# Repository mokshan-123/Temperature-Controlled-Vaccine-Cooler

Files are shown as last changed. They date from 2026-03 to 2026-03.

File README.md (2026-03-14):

# Smart Vaccine Temperature Monitoring System

A portable, low-cost vaccine temperature monitoring system designed for cold-chain transport in rural and low-resource settings.  
The system provides real-time temperature monitoring, configurable safety thresholds, and wireless alerts using ESP-NOW communication.

---

## 1. Overview

Vaccines must be maintained within a strict temperature range (typically 2–8°C) to preserve potency. During transportation(especially in rural outreach) temperature excursions may go undetected, leading to vaccine spoilage and wastage.

This project presents a smart monitoring solution that:

- Continuously measures internal temperature
- Wirelessly transmits data without Wi-Fi infrastructure
- Provides visual and audio alerts for temperature excursions
- Allows configurable temperature thresholds
- Operates on rechargeable battery power

The system is designed to be affordable, modular, and suitable for low-resource healthcare environments.

---

## 2. System Architecture

The system consists of two main subsystems:

### Transmitter Unit (Inside Vaccine Box)
- ESP8266 NodeMCU
- DS18B20 Digital Temperature Sensor
- Battery-powered
- Sends temperature data via ESP-NOW

### Receiver Unit (External Monitoring Module)
- ESP32-S3
- 0.96" OLED Display
- 4x4 Keypad for threshold configuration
- LED indicators (Safe / Warning / No Data)
- Active buzzer for alerts
- Receives data via ESP-NOW

### Communication Protocol
- ESP-NOW (peer-to-peer wireless protocol)
- No internet or router required
- Low-latency and energy-efficient

---

## 3. Key Features

- Real-time temperature monitoring
- Configurable upper and lower thresholds
- OLED live temperature display
- LED status indicators:
  - Green → Within safe range
  - Red (blinking) → Temperature excursion
  - Yellow → No data received
- Audible buzzer alerts
- Automatic timeout detection
- Battery-powered operation
- Designed for future Peltier cooling integration

---

## 4. Hardware Components

### Core Electronics
- ESP8266 NodeMCU (Transmitter)
- ESP32-S3 (Receiver)
- DS18B20 Waterproof Digital Temperature Sensor
- 0.96” OLED Display (I2C)
- 4x4 Matrix Keypad
- Active Buzzer
- LED Indicators
- 18650 Li-ion Battery
- Boost Converter Module

### Enclosure
- Insulated vaccine compartment
- Receiver housing with display and keypad
- Provision for future Peltier module integration

---

## 5. Firmware Architecture

### Transmitter Firmware (ESP8266)

Responsibilities:
- Initialize DS18B20 sensor
- Read temperature every 1 second
- Package data into structured format
- Transmit via ESP-NOW
- Handle sensor disconnection errors

Core logic:
- OneWire + DallasTemperature library
- ESP-NOW peer configuration
- Periodic data transmission

---

### Receiver Firmware (ESP32-S3)

Responsibilities:
- Receive temperature data via ESP-NOW callback
- Store latest reading
- Compare against user-defined thresholds
- Control buzzer and LED indicators
- Display temperature and limits on OLED
- Handle timeout detection (no data condition)
- Allow threshold input via keypad

Key Embedded Concepts Used:
- Interrupt-driven callback for wireless reception
- State-based LED logic
- Non-blocking buzzer toggling using millis()
- Timeout monitoring for communication reliability

---

## 6. Threshold Configuration

Users can enter threshold-setting mode using the keypad:

- Lower threshold input
- Upper threshold input
- Automatic correction if upper < lower
- Real-time display update

This allows flexibility for different vaccine temperature requirements.

---

## 7. Testing and Validation

The prototype was evaluated under lab and field-like conditions.

### Results

- Wireless range: 20–30 meters (line-of-sight)
- Sensor accuracy deviation: approximately ±0.5°C (compared to calibrated thermometer)
- Reliable threshold detection and alert triggering
- Stable OLED readout
- Sufficient battery performance for continuous monitoring

---

## 8. Regulatory Considerations

The device is intended as a low-risk monitoring accessory for vaccine cold-chain systems.

Likely classification:
- Class I (low-risk monitoring device)

Relevant standards considered:
- IEC 60601 (Electrical safety considerations)
- IEC 62304 (Medical device software lifecycle)
- WHO cold-chain guidelines
- Local Ministry of Health compliance requirements

Future iterations would require:
- Sensor validation testing
- Electrical safety compliance
- EMC testing
- Software documentation per medical device standards

---

## 9. Hardware Overview

### Circuit Diagram
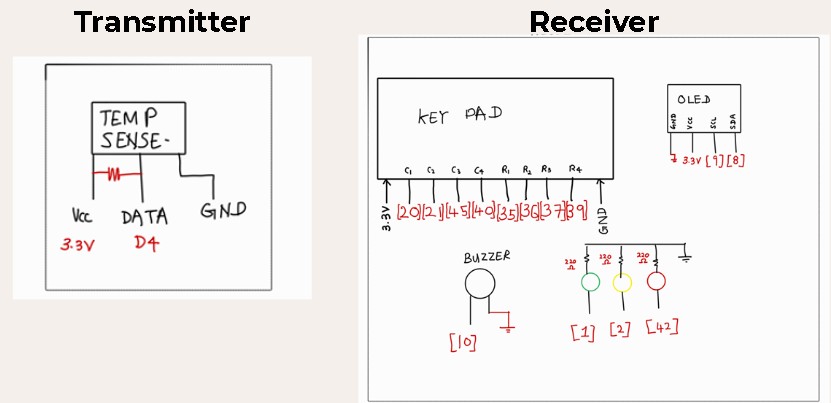
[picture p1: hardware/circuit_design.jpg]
Circuit


### Block Diagram
Block_diagram

### PCB Layout
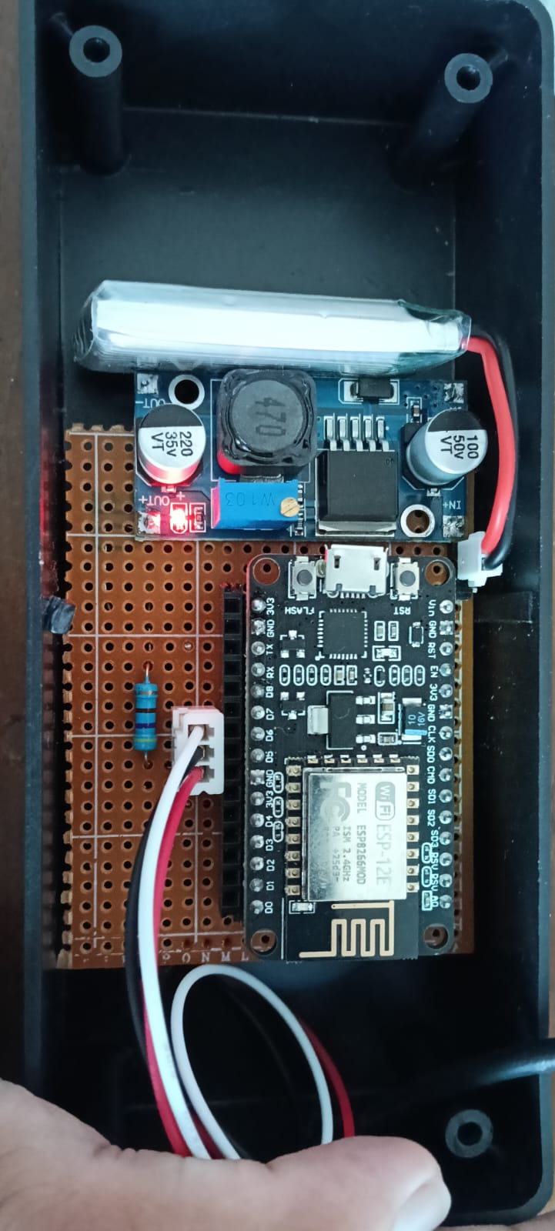
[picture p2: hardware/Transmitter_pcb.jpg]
Transmitter_PCB

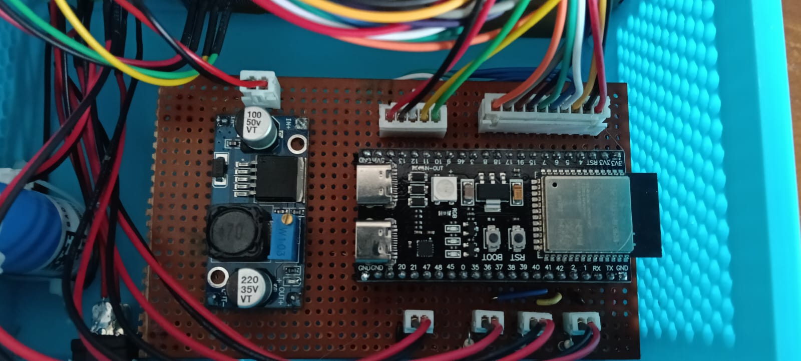
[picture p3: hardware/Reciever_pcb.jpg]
Reciever_PCB


### Enclosure Design
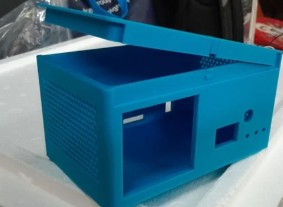
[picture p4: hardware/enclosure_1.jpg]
Enclosure_1

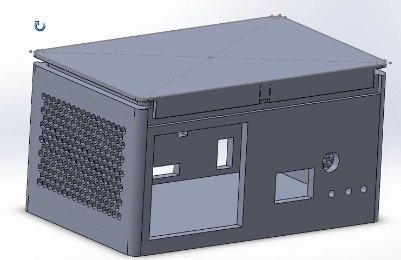
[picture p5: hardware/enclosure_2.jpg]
Enclosure_2

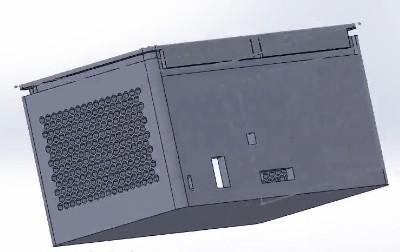
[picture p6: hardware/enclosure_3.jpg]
Enclosure_3


### Final product Assembly
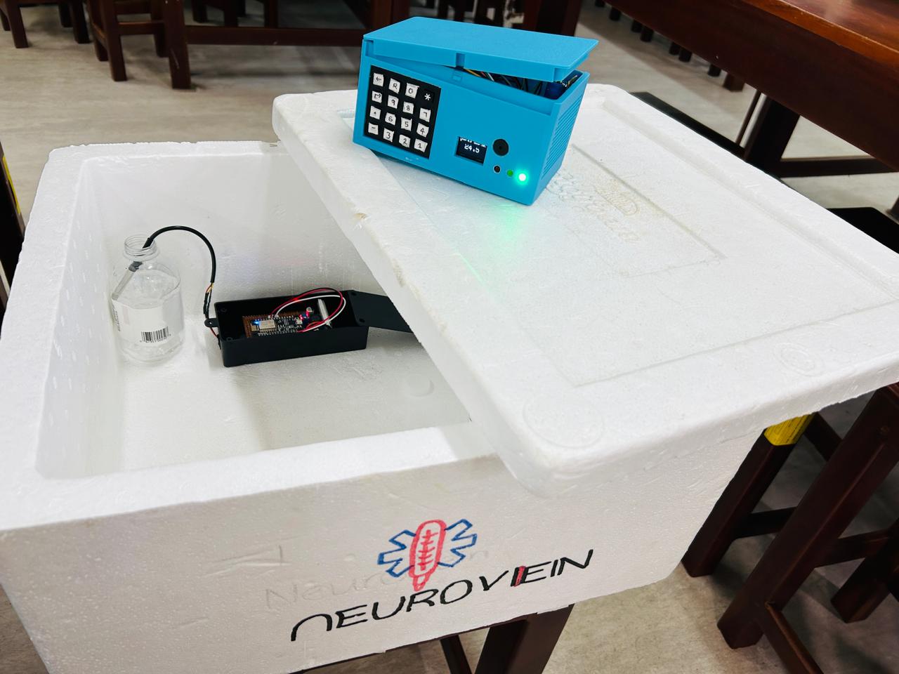
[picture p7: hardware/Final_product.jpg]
Final Product


---

## 10. Future Improvements

- Integration of Peltier-based active cooling
- Multi-sensor internal thermal mapping
- Solar charging module for remote deployment
- Cloud-based data logging
- Fault detection for sensor and communication errors
- Improved insulation materials
- Secure encrypted ESP-NOW transmission

---

## 11. Budget Summary

Total prototype cost: ~8410 LKR

Major cost contributors:
- ESP32-S3
- Enclosure materials
- Insulated structure
- Battery system

The system was designed to remain affordable for low-resource healthcare settings.

---

## 12. Contributors
- Colombage DM (me)– Circuit design, algorithm development, PCB soldering
- Abdul Rahman – Wireless communication configuration, enclosure design
- Abishek L – Mobile application development
- Suresh S – Documentation

University of Moratuwa  
Department of Electronic & Telecommunication Engineering  
BM2210 – Biomedical Device Design

---

## 13. License

This project is released under the MIT License.

---

## 14. Disclaimer

This project is a prototype developed for academic purposes.  
It is not certified for clinical or commercial medical use.  
Further validation and regulatory approval would be required for real-world deployment.

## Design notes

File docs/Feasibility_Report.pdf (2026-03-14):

## DEPARTMENT OF ELECTRONIC &

TELECOMMUNICATION ENGINEERING,

## UNIVERSITY OF MORATUWA

# BM 2210 - Biomedical Device Design Feasibility Report: Temperature-Controlled Medicine and Vaccine Cooler Box

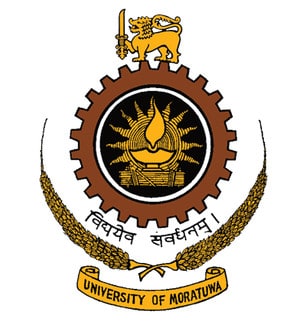
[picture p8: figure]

## Group C

## COLOMBAGE DM 230108U

RAHMAN MFA | 230507R
ABISHEK L | 230016K
SANTHOSH S | 230581K

## Contents

1 Introduction | 2
2 Need Statement | 2
3 Ideation | 3
4 Initial Concept Selection | 4
5 Concept Screening | 5
6 Business Model | 6
7 Concept Testing | 8
8 Final Concept Selection | 9
9 Conclusion | 10
10 Appendix | 11

## 1 Introduction

Vaccines must be maintained within a narrow temperature range (typically 2–8 ◦C) to remain effective. Current cold-chain solutions are either expensive or unsuitable for low-resource and remote settings. Our project aims to develop a portable, low-cost, temperature-controlled vaccine carrier that integrates real-time temperature monitoring, user alerts, and a prototypelevel active cooling mechanism using a Peltier module with fan and heat sinks. This feasibility study documents the ideation, screening, testing, and final selection process for the concept.

## 2 Need Statement

Vaccines must be maintained within their specific required temperature range to remain effective. However, in rural outreach and long-distance transport, the vaccine supply chain is often disrupted without timely detection. There is a clear need for an affordable, portable solution that ensures continuous real-time monitoring of vaccines during transportation.

### 2.1 Problem

During transportation, healthcare workers often remain unaware if vaccine temperatures fluctuate beyond safe limits. This results in wastage of doses, reduced effectiveness, and potential outbreaks of preventable diseases. The challenge is especially critical in rural and low-resource settings where reliable monitoring systems are limited.

### 2.2 Existing Solutions

- Passive vaccine carriers/cold boxes: Low cost and rugged but provide no real-time temperature feedback and because of the usage of ice packs, the required temperature range is unreliable.
- Electronic temperature loggers: Record excursions but only retrospectively; spoilage is often discovered too late.
- Active compressors or solar-powered cold boxes: Provide reliable regulation but are expensive, heavy, and unsuitable for last-mile campaigns.

### 2.3 Proposed Solution

We aim to develop a portable vaccine carrier with built-in digital temperature monitoring, real-time alerts, and an active cooling mechanism. The system will:

- Allow input of the temperature range required for the particular vaccine to be transported via mobile app or dial pad.
- Continuously measure the vaccine’s temperature with embedded sensors.
- Send live data to a mobile application and trigger alarms when excursions occur.
- Activate a Peltier-based cooling mechanism with fan and heat sinks to bring the temperature back within the safe range after an excursion is detected.

- Provide automated data logging for compliance and tracking.
- Remain lightweight, affordable, and practical for rural and last-mile vaccine delivery.

This approach directly addresses the limitations of existing solutions by offering a mid-cost, reliable tool for healthcare workers. By reducing vaccine wastage and ensuring safe immunization, it contributes to improved public health outcomes in both local and global contexts.

### 2.4 Validation

This need was highlighted during discussions with Dr. V. Kayalvili, Director of Trincomalee General Hospital, Sri Lanka. She emphasized that in rural outreach, vaccine transport frequently faces challenges due to inadequate monitoring, leading to potential wastage and compromised immunization.

## 3 Ideation

A brainstorming session was conducted on 10th September 2025 to generate possible solutions for safe vaccine transport. The initial ideas are summarized in the following ideation diagram.

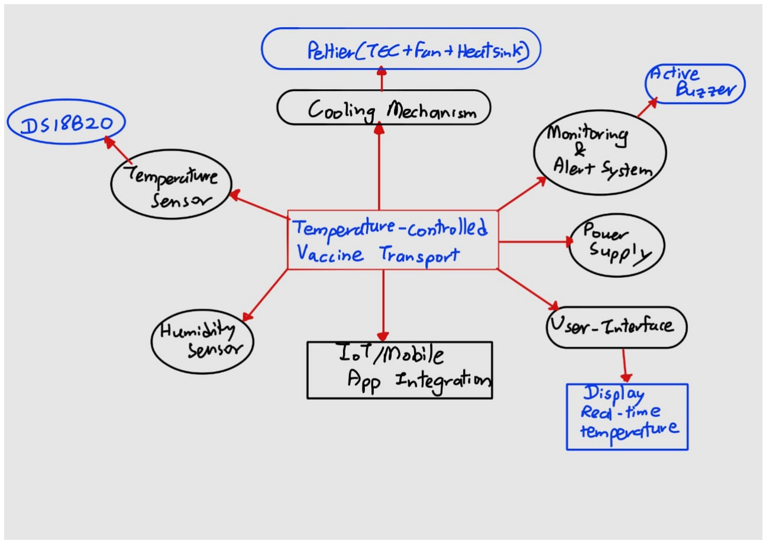
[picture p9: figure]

Figure 1: Brainstorm of Ideation

## 4 Initial Concept Selection

From the above ideation, several possible directions were generated to address the identified need. Ideas that were impractical, too costly, or unsuited to rural deployment were filtered out, leaving us with a smaller set of viable approaches for further consideration.
Cooling Mechanisms: We considered multiple approaches to maintain the vaccine temperature within the required 2–8◦C range. Passive cooling using ice packs or phase change materials offers simplicity and low cost but provides no control or real-time adjustment once deployed. Active cooling using a Peltier module with a fan and heat sink was also discussed, as it allows direct electronic control and can be scaled down for a prototype. A hybrid approach that combines passive insulation with active Peltier cooling offers a balance between low cost and controllability.
Monitoring and Alerts: Digital temperature monitoring was identified as a core requirement. Concepts included integrating sensors such as DS18B20 or thermistors to continuously log temperature, display it on an LCD screen, and provide local alerts through buzzer/LEDs. Additionally, mobile app or Bluetooth connectivity was proposed to enable remote notifications, ensuring healthcare workers are aware of any temperature excursions.
Power Supply: Since last-mile transport often lacks reliable electricity, several power supply concepts were considered. Rechargeable Li-ion batteries provide portability, while DC supply is practical for initial prototyping. A solar-powered option was also discussed as a long-term sustainable solution, though cost and efficiency constraints remain challenges at the prototype stage.
User Interface: To ensure usability, the team considered different input and display options. A simple keypad for entering threshold limits and an LCD display for real-time feedback were seen as the most practical choices for the prototype. Mobile app integration was identified as an additional option for future iterations, enabling remote monitoring and data logging. Affordability and Practicality: Finally, practical considerations guided our initial concept selection. The device must remain lightweight, modular, and affordable to be viable in rural outreach programs. This eliminated bulky compressor-based cooling systems and narrowed the focus toward Peltier-based prototypes combined with smart monitoring and rechargeable power supply.
In summary, the initial concept selection process clustered and refined ideas from the brainstorming session into four main domains: cooling mechanism, monitoring and alerts, power supply, and user interface. These selected directions form the basis of the concepts carried forward into the screening and testing stages.

### 4.1 Screening Against Need Criteria

The brainstormed ideas were compared against the defined need criteria to evaluate their suitability. Table 1 summarizes the assessment.

Table 1: Screening of concepts against need criteria
Concept | Effectiveness | Portability | Affordability | Reliability | Usability
Passive Cooling (Ice/PCM) | ✓ | ✓ | ✓ | × | ✓
Active Cooling (Peltier + Fan) | ✓ | ✓ | × | ✓ | ✓
Hybrid (Passive + Peltier) | ✓ | ✓ | × | ✓ | ✓
Smart Monitoring (Sensors + Alerts) | ✓ | ✓ | ✓ | ✓ | ✓
IoT / Mobile App Integration | ✓ | ✓ | × | ✓ | ×
Battery Power | ✓ | ✓ | ✓ | × | ✓
Solar Power Option | ✓ | × | × | ✓ | ✓

## 5 Concept Screening

### 5.1 Intellectual Property (IP)

### 5.1.1 Temperature Monitoring System

The proposed device includes an integrated temperature sensing system that ensures real-time monitoring of the internal conditions of the vaccine carrier. This feature is essential for maintaining the required temperature range for vaccine storage, preventing spoilage and loss of efficacy.

How it Operates:
Temperature Sensors: High-precision digital temperature sensors are placed inside the vaccine box to continuously measure the internal temperature.

Data Processing: Sensor readings are processed by a microcontroller, which compares the measured temperature against the pre-set safe range for vaccines.

Alert System: If the temperature deviates from the acceptable range, the system immediately notifies the user through audible alarms, visual indicators, or mobile alerts. This ensures timely corrective action.

User interface with keypad input: A simple keypad is provided on the device, enabling users to manually set temperature thresholds.

### 5.1.2 Cooling Control with Peltier Modules

The cooling mechanism of the device uses thermoelectric (Peltier) modules, which provide a compact and efficient method of active cooling. This ensures the internal environment remains within the required range even in warm external conditions

How it Works: Peltier Cooling: Peltier modules generate a cooling effect when an electric current is applied. These modules are strategically installed in the carrier walls.

Heat Dissipation: A heat sink and fan assembly are used on the hot side of the Peltier to efficiently dissipate excess heat.

Automatic Regulation: The microcontroller adjusts the Peltier power based on real-time sensor readings, optimizing energy use and maintaining stable internal temperature

### 5.1.3 Mobile Application Integration

To enhance usability and provide real-time remote monitoring, the system is integrated with a dedicated mobile application. This ensures that healthcare workers can continuously track and manage vaccine safety even while on the move.

How it Works: Real-Time Data Display: The mobile app receives continuous temperature data from the vaccine carrier via Bluetooth/Wi-Fi. The user can view current internal conditions on their smartphone in real time

User Control: Through the app, users can set or modify safe temperature thresholds for different types of vaccines. The system automatically applies these settings for monitoring and regulation

Smart Notifications: If the temperature goes out of the safe range, the app instantly alerts the user through push notifications, vibration, or sound alerts.
Data Logging: Temperature history is stored in the app, enabling record-keeping for regulatory compliance and future reference.

Remote Adjustment: Users can remotely adjust cooling levels and operational settings, ensuring flexibility and reliability in diverse environments.

### 5.2 Regulation

According to FDA classifications, this device would most likely be considered a low-risk Class I medical device, similar to medical refrigerators and vaccine temperature monitors. Such devices are generally subject only to general controls and are often exempt from premarket notification (510(k)), provided they do not make novel or high-risk claims. For deployment in Sri Lanka, the system must comply with Ministry of Health (MOH) cold-chain policies as well as the World Health Organization Performance, Quality, and Safety (WHO PQS) standards for vaccine carriers and temperature monitoring equipment. Meeting these requirements will be critical for future adoption in immunization programs and international procurement.

## 6 Business Model

Since Sri Lanka will be the first region of deployment, the business model must align with local healthcare infrastructure, resource availability, and economic conditions. The approach focuses on providing healthcare workers with practical, easy-to-use tools to ensure safe vaccine transport, while leveraging modular design and affordable components.

### 6.1 Temperature Monitoring Subsystem

Accurate and continuous temperature monitoring is essential to prevent vaccine spoilage. By integrating digital sensors (DS18B20) with microcontrollers, the system provides real-time readings accessible via an LCD or mobile app. This subsystem adds value by:

- Reducing human error in temperature tracking.
- Enabling automated data logging for compliance and reporting.
- Offering a modular solution that can be upgraded or replaced independently.

The business model here emphasizes capital equipment with optional service subscriptions for maintenance, ensuring reliable sensor performance over time.

### 6.2 Alert System Subsystem

The alert system, including buzzer, LED indicators, and mobile push notifications, enhances user awareness when temperature excursions occur. This subsystem provides value by:

- Delivering immediate, actionable feedback to healthcare workers.
- Reducing vaccine wastage and mitigating public health risks.
- Complementing existing monitoring systems without major workflow changes.

The business model leverages a reusable product with low-cost upgrades, allowing healthcare providers to adopt the alert system as an add-on to existing carriers or as part of the complete package.

### 6.3 Active Cooling Subsystem (Peltier Module)

The Peltier-based cooling module actively maintains internal temperature within the safe range. Value propositions include:

- Compact, energy-efficient cooling suitable for remote transport.
- Scalable integration with varying carrier sizes.
- Reduced dependency on passive ice packs, enhancing portability.

The business model for this subsystem focuses on capital equipment sales with optional local assembly to reduce costs. High-usage units may adopt a leasing or service model to cover maintenance of cooling components.

### 6.4 Power Supply Subsystem

The device’s rechargeable Li-ion battery or DC power supply ensures continuous operation in low-resource settings. This subsystem contributes to business value by:

- Allowing flexible deployment in areas without grid access.
- Supporting modular upgrades or replacement of battery packs.
- Ensuring consistent operation of cooling and monitoring subsystems.

The business model incorporates reusable components with recurring maintenance or battery replacement service, maintaining sustainability and uptime.

### 6.5 Mobile Application Integration

The mobile app provides remote monitoring, threshold configuration, and historical data access. Its business value is:

- Enabling centralized data collection for reporting and regulatory compliance.
- Supporting multiple vaccine types with configurable thresholds.
- Offering a platform for future upgrades, including cloud storage and analytics.

The business model relies on a software subscription model, with basic functionality included with the device and premium features (cloud analytics, multi-device management) available as optional paid services.

### 6.6 Summary

By analyzing each subsystem individually, the business model ensures that the temperature-controlled vaccine carrier provides both immediate and long-term value to healthcare workers and institutions. Each subsystem can be scaled, upgraded, or serviced independently, creating a flexible, sustainable, and locally appropriate solution for Sri Lanka’s vaccine transport challenges.

## 7 Concept Testing

### 7.1 Prototyping

In our proposed solution prototype, we primarily have two main components: the temperature monitoring and alerting system and the active cooling mechanism.
For the monitoring and alerting subsystem, we plan to use a digital temperature sensor (DS18B20) to measure the internal temperature of the carrier. The sensor data will be processed by a microcontroller (ESP32/Arduino), which allows the user to input the desired temperature range through a keypad or mobile interface. If the measured temperature goes outside the defined safe range, the system will trigger a buzzer and LED to provide an immediate alert. An LCD display will also be used to show real-time readings and status messages.
For the cooling subsystem, we intend to use a Peltier thermoelectric module paired with a heat sink and cooling fan. Thermal paste will be applied to improve heat transfer efficiency. When an out-of-range temperature is detected, the microcontroller will automatically activate the Peltier module via a driver circuit (MOSFET or motor driver). This will actively reduce the internal temperature until it stabilizes within the safe range.
The prototype integrates these subsystems into a compact insulated box, powered by a DC supply or rechargeable battery. The block diagram of the proposed prototype architecture is shown in Figure.

### 7.2 Testing Plan

The prototype will be tested for:

- Sensor accuracy under lab conditions.

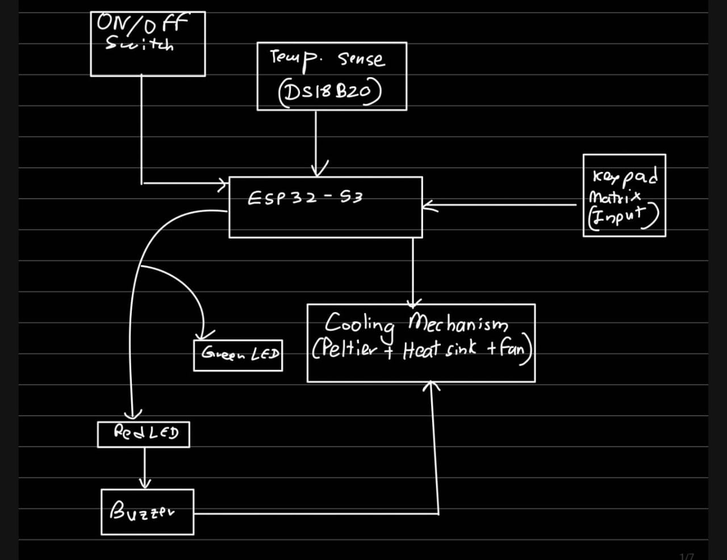
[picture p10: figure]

Figure 2: Block diagram of the proposed vaccine carrier prototype

- Cooling performance inside an insulated container at 30–37 ◦C ambient.
- Alarm responsiveness when thresholds are exceeded.
- Battery runtime and power consumption efficiency.

## 8 Final Concept Selection

### 8.1 Killer Risks

- Temperature Control Failure: Peltier or fan failure could let temperatures go outside 2–8◦C.
- Power / Battery Failure: Insufficient battery capacity or charger issues could stop cooling.
- Sensor / Monitoring Malfunction: ESP32-S3 could give inaccurate or no readings.
- Overheating of Electronics: Hot side of Peltier could damage electronics if heat isn’t dissipated properly.
- Mechanical / Structural Failure: Poor insulation or enclosure could compromise temperature stability.
- Regulatory / Compliance Risk: Failing to meet WHO or local vaccine cold chain standards.
- Environmental Risks: Extreme ambient temperature, humidity, or vibration affecting performance.

### 8.2 Selection Matrix with Ranks and Scores

The selection matrix (Table above) confirms that the Peltier-based portable vaccine carrier with monitoring and alerts best balances effectiveness, affordability, and feasibility. With the above subsystem analysis, the feasibility of different concepts for our temperature-controlled vaccine carrier is summarized below. The abbreviations used in the matrix are as follows:

- IP - Intellectual Property
- RR - Regulatory Requirements
- RI - Reimbursement / Cost-effectiveness
- BM - Business Model

The objective and concept abbreviations are given below:

- (01) Active Cooling with Peltier + Fan
- (02) Smart Temperature Monitoring + Alerts
- (03) Hybrid: Passive Cooling + Active Peltier

Table 2: Subsystem Analysis for Feasibility Considerations
Subsystem / Concept | IP | RR | RI | BM
Active Cooling (Peltier + Fan) Smart Temperature Monitoring + Alerts Hybrid: Passive + Peltier | ✓ ✓ ✓ | ✓ ✓ ✓ | × ✓ × | ✓ ✓ ✓

Table 3: Weighted Objectives and Concept Screening
Objective | Weight | (01) | (02) | (03)
Accuracy (maintain 2–8◦C) Portability Continuous Monitoring Affordability Usability / Ease of Deployment | 5 3 4 3 2 | +1 0 0 0 +1 | +1 +1 +1 +1 +1 | +1 +1 0 0 0
Weighted Score | – | 7 | 11 | 5
Rank | – | 2 | 1 | 3

## 9 Conclusion

This report documents the systematic process of concept generation, screening, testing, and selection for a temperature-controlled vaccine carrier. The chosen Peltier-based design offers a promising prototype pathway, addressing the need for safe, affordable, and portable vaccine transport in low-resource settings. Future work will focus on improving cooling efficiency, insulation, and extended battery operation.

## References

[1] World Health Organization. Unit 4: Cold chain and logistics management. Immunization Handbook. WHO, 2025.
[2] World Health Organization. Vaccine Management Handbook. Technical guidance on immunization logistics. Published July 2025.
[3] Centers for Disease Control and Prevention. Vaccine Storage and Handling Toolkit. January 2023.
[4] Gilero. Medical Device Classification - Overview of 3 Classes. August 2025. Explains FDA Class I, II, III medical devices.
[5] Dallas Semiconductor. DS18B20 Programmable Resolution 1-Wire Digital Thermometer Datasheet.
[6] Matsusada Precision. Thermoelectric Coolers by Peltier. June 2023. Overview of thermoelectric cooling applications.

## 10 Appendix

- Appendix A: Brainstorming sketches, notes and concept maps

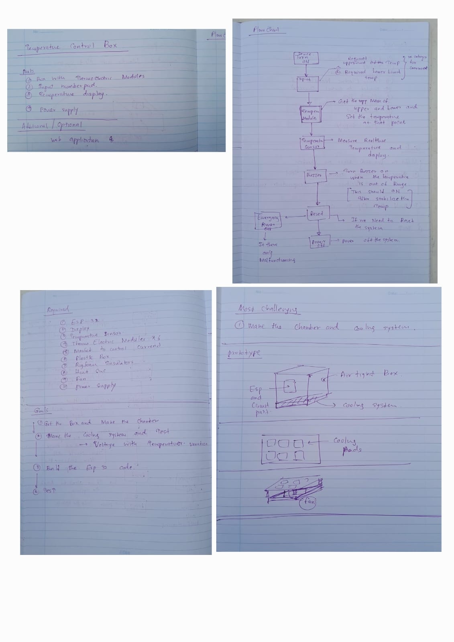
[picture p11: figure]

Figure 3: Brainstorm sketches and notes

- Appendix B: Selection matrix with raw scores

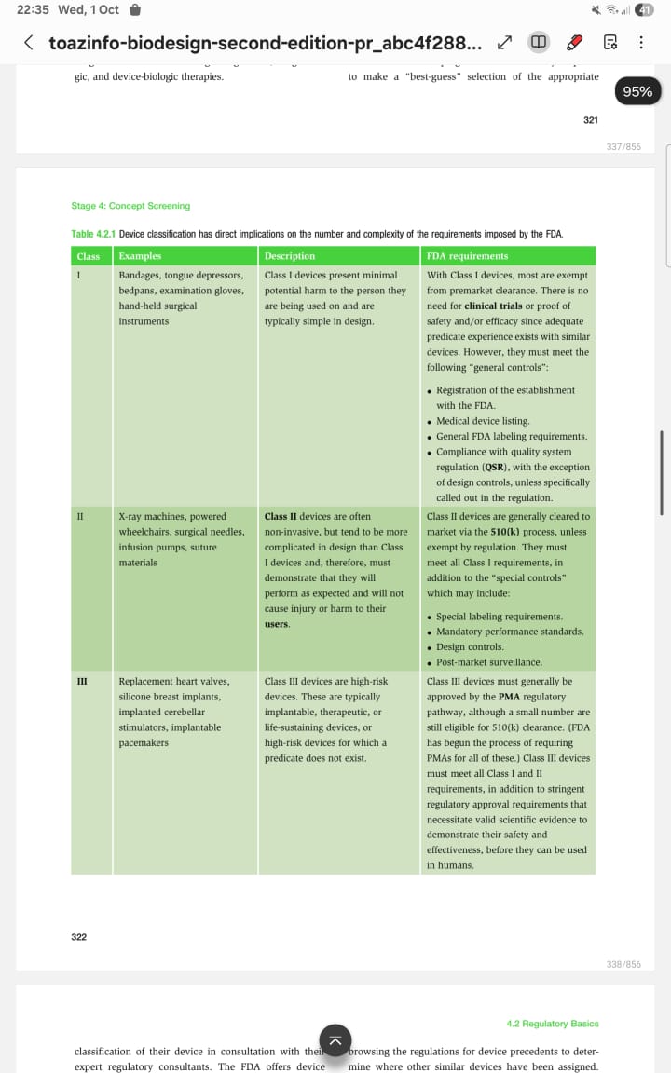
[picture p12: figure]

Figure 4: Source : ”Biodesign: The Process of Innovating Medical Technologies”

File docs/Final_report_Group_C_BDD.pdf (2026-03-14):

## DEPARTMENT OF ELECTRONIC &

TELECOMMUNICATION ENGINEERING,

## UNIVERSITY OF MORATUWA

# BM 2210 - Biomedical Device Design Project Report: Temperature-Controlled Medicine and Vaccine Cooler Box

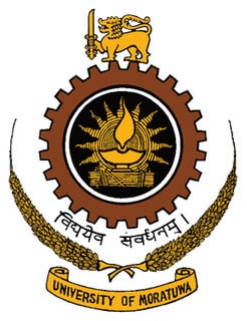
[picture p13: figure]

## Group C

## COLOMBAGE DM 230108U

RAHMAN MFA | 230507R
ABISHEK L | 230016K
SANTHOSH S | 230581K

## Contents

1 Introduction | 2
2 Need Statement | 2
3 Proposed Solution | 2
4 Methodology | 3
5 Device Details | 4
6 Simulation Results | 13
7 Prototype and Testing | 13
8 Possible Regulatory Pathway | 14
9 Final Budget | 15
10 Task Allocation | 15
11 Conclusion and Final Product | 16
12 Future Improvements | 16

## 1 Introduction

Vaccines must remain within 2–8◦C to preserve potency. However, during field transportation—particularly in rural outreach—healthcare workers lack real-time visibility to detect temperature excursions promptly. Existing passive cold boxes, ice packs, data loggers, and solar fridges fail to provide an affordable, lightweight, continuous monitoring solution.
This project proposes a portable, low-cost vaccine transport monitoring system featuring digital temperature sensing, wireless transmission, configurable thresholds, and immediate alerts. A Peltier-based cooling system was planned but not implemented due to time constraints; it is included under future improvements.

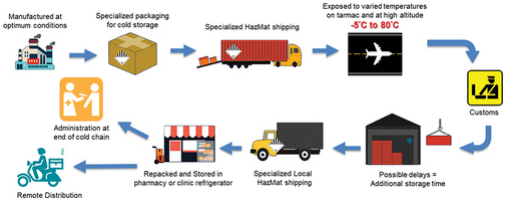
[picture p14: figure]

Figure 1: Illustration of vaccine cold-chain workflow (Insert relevant image)

## 2 Need Statement

“A way to maintain safe temperature conditions for temperature-sensitive vaccines during transport for healthcare workers in rural and low-resource settings to improve the reliability of vaccine delivery.”

## 3 Proposed Solution

The proposed solution is a Smart Vaccine Temperature Monitoring System designed to operate independently of external networks using ESP-NOW. The system includes:

- A DS18B20 digital temperature sensor placed inside the insulated vaccine chamber.
- An ESP8266 microcontroller acting as the transmitter inside the box.
- ESP-NOW-based wireless communication to a remote ESP32-S3 receiver.
- An OLED display for real-time readouts.
- Configurable upper and lower temperature thresholds via a 4x4 keypad.
- Visual and audio alerts (LED + buzzer) when excursions occur.
- A basic mobile app to receive notifications and temperature data.

This hybrid approach balances cost, simplicity, and functionality without depending on mobile networks or Wi-Fi infrastructure.

## 4 Methodology

### 4.1 Design Flow

The project followed the structured BM2210 biomedical device design process. Each stage contributed to developing a practical, affordable solution suitable for real-world field conditions.

### 1. Need Identification

A review of cold-chain challenges in Sri Lanka and global rural vaccination programs highlighted that temperature excursions commonly go unnoticed during transport. Interviews with healthcare workers and analysis of WHO cold-chain reports confirmed the need for an affordable, real-time monitoring solution.

### 2. Ideation

Multiple approaches were brainstormed, including fully passive insulation upgrades, sensoronly monitoring systems, Bluetooth/Wi-Fi connected devices, and hybrid active–passive solutions. Constraints such as cost, weight, power consumption, and field usability guided the ideation process.

### 3. Concept Selection

Candidate concepts were evaluated using feasibility criteria: technological complexity, component availability, user training requirements, cost, and durability. The hybrid digital monitoring system with optional active cooling (Peltier) was selected as it offered the best balance between practicality and performance.

### 4. Prototyping

Subsystems—including sensor circuitry, ESP-NOW communication links, keypad threshold input, alarm mechanisms, and enclosure layout—were developed and tested incrementally. A functional prototype incorporating all essential features was assembled using available components.

### 5. Testing

The prototype was tested in both controlled and outdoor conditions to evaluate wireless range, temperature measurement stability, alert responsiveness, and battery performance. Simulated excursions verified correct activation of thresholds and communication between transmitter and receiver.

### 6. Refinement

Based on test results, improvements were made to code efficiency, display readability, alarm timing, and enclosure insulation. The Peltier cooling subsystem was postponed for future work due to time constraints but left structurally supported within the design for later integration.

### 4.2 Block Diagram

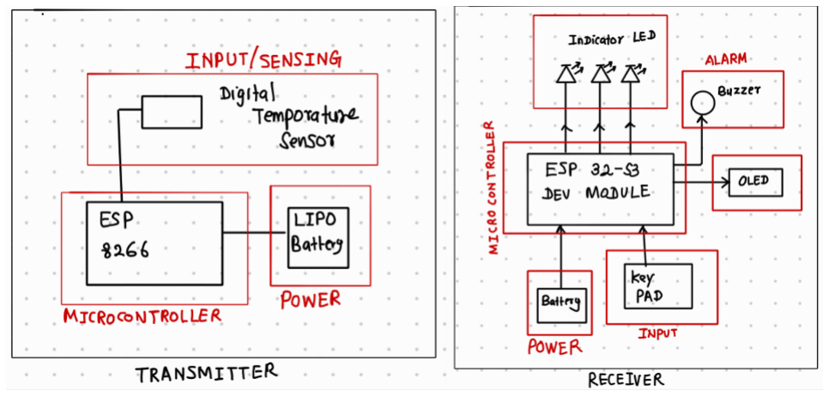
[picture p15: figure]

Figure 2: System block diagram showing transmitter and receiver

## 5 Device Details

### 5.1 Component Selection

Components used include:

- ESP8266 NodeMCU (Transmitter)
- ESP32-S3 (Receiver)
- DS18B20 digital temperature sensor
- 4x4 matrix keypad
- 0.96” OLED display (I2C)
- Active buzzer and LED indicators
- 18650 Li-ion battery with boost converter

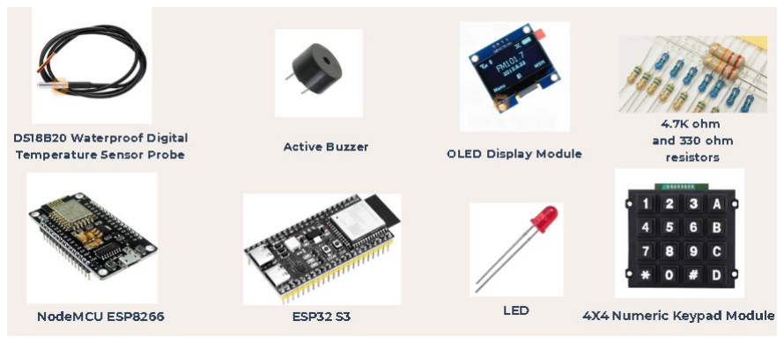
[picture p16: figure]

Figure 3: Major components used in the system (Part 1)

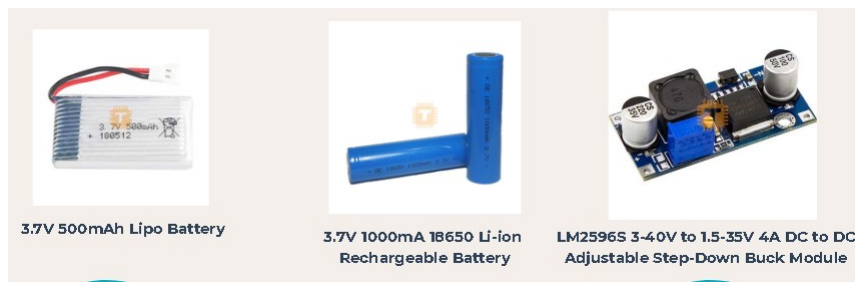
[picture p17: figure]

Figure 4: Major components used in the system (Part 2)

### 5.2 Circuit Diagrams


Figure 5: Transmitter circuit diagram

### 5.3 Enclosure Design

The enclosure was designed to securely house the transmitter, receiver, sensors, and other electronics while providing insulation for the vaccine compartment. The design focused on:

- Proper spacing for airflow and heat dissipation.
- Easy access for battery replacement and component maintenance.
- Mounting provisions for the buzzer, LEDs, keypad, and OLED display.
- Compatibility with future Peltier cooling integration.
- Lightweight and durable material selection for portability.


Figure 6: Front view of the Enclosure


Figure 7: Side view

### 5.4 PCB Layout


Figure 8: Transmitter PCB / veroboard layout


Figure 9: Receiver PCB / veroboard layout

### 5.5 Software Code (ESP-NOW Implementation)

Below is the core transmitter logic:

#include <ESP8266WiFi.h>

#include <espnow.h>

#include <OneWire.h>

#include <DallasTemperature.h>

// ===============================
// DS18B20 Setup
// =============================== #define ONE_WIRE_BUS 2 // D4 = GPIO2 OneWire oneWire(ONE_WIRE_BUS); DallasTemperature sensors(&oneWire);

// ===============================
// Receiver MAC Address (ESP32-S3)
// ===============================
uint8_t receiverMAC[] = {0x30, 0xED, 0xA0, 0xB9, 0xCD, 0xE0};

// =============================== // Data Structure
// =============================== typedef struct struct_message { float temperature;
} struct_message;

struct_message data;

// =============================== // Setup
// =============================== void setup() {
Serial.begin(115200);
sensors.begin();

WiFi.mode(WIFI_STA); // MUST be station mode for ESP-NOW

if (esp_now_init() != 0) {
Serial.println("Error initializing ESP-NOW"); return;
}

// Set device role
esp_now_set_self_role(ESP_NOW_ROLE_CONTROLLER);

// Add receiver peer
if (esp_now_add_peer(receiverMAC, ESP_NOW_ROLE_SLAVE, 1, NULL, 0) != 0) {
Serial.println("Failed to add peer");
return;
}

Serial.println("ESP8266 DS18B20 Transmitter Ready"); }

// =============================== // Loop
// =============================== void loop() {
sensors.requestTemperatures();

float tempC = sensors.getTempCByIndex(0);

if (tempC == DEVICE_DISCONNECTED_C) { Serial.println("DS18B20 Error: Sensor not detected"); delay(1000);
return;
}

data.temperature = tempC;

// Send structure via ESP-NOW
esp_now_send(receiverMAC, (uint8_t *)&data, sizeof(data));

Serial.printf("Sent -> Temperature: %.2f C\n", data.temperature);

delay(1000);
}

Below is the receiver code logic:

#include <WiFi.h>

#include <esp_now.h>

#include <Keypad.h>

#include <Wire.h>

#include <Adafruit_GFX.h>

#include <Adafruit_SSD1306.h>

// =============================== // OLED SETUP
// =============================== #define SCREEN_WIDTH 128
#define SCREEN_HEIGHT 64

#define OLED_RESET | -1

#define SDA_PIN 8

#define SCL_PIN 9

Adafruit_SSD1306 display(SCREEN_WIDTH, SCREEN_HEIGHT, &Wire, OLED_RESET);

// ===============================
// Transmitter MAC Address (ESP8266)
// ===============================
uint8_t senderMAC[] = {0xEC, 0xFA, 0xBC, 0xCA, 0x2A, 0xF3};

// ===============================
// Data Structure
// ===============================

typedef struct struct_message { float temperature;
} struct_message;

struct_message incomingData; bool dataReceived = false; unsigned long lastPacketTime = 0; #define DATA_TIMEOUT 2000

// =============================== // Keypad Setup
// =============================== #define ROWS 4
#define COLS 4

char keyMap[ROWS][COLS] = { {’1’,’2’,’3’,’A’},
{’4’,’5’,’6’,’B’},
{’7’,’8’,’9’,’C’},
{’#’,’0’,’*’,’D’}
};
byte rowPins[ROWS] = {35, 36, 37, 39};
byte colPins[COLS] = {20, 21, 45, 40};
Keypad keypad = Keypad(makeKeymap(keyMap), rowPins, colPins, ROWS, COLS);

// ===============================
// Thresholds
// =============================== float lowerThreshold = 0.0; float upperThreshold = 100.0; bool thresholdsSet = false;
bool inThresholdInput = false;

// =============================== // BUZZER AND LED SETUP
// =============================== #define BUZZER_PIN 10
bool buzzerActive = false; unsigned long lastBuzzToggle = 0; bool buzzState = false;

#define GREEN_LED 1

#define YELLOW_LED 2

#define RED_LED 42

unsigned long lastRedBlink = 0; bool redState = false;

// ===============================
// Callback when data is received
// ===============================
void OnDataRecv(const esp_now_recv_info_t *recv_info, const uint8_t

*incomingDataBytes, int len) {
memcpy(&incomingData, incomingDataBytes, sizeof(incomingData)); dataReceived = true;
lastPacketTime = millis();

if (!inThresholdInput && thresholdsSet) {
float temp = incomingData.temperature;
if (temp < lowerThreshold) Serial.println("Low Temp");
else if (temp > upperThreshold) Serial.println("High Temp"); else Serial.println("In Range");

buzzerActive = (temp < lowerThreshold || temp > upperThreshold); if (!buzzerActive) digitalWrite(BUZZER_PIN, LOW);
}
}

// ===============================
// Function to input float via keypad
// ===============================
float inputFloatValue(const char* prompt, bool isLower) { Serial.print(prompt);
String inputStr = "";
bool negative = false;
bool decimalPointUsed = false;

display.clearDisplay();
display.setTextSize(1);
display.setCursor(0,0);
display.print(isLower ? "Lower Threshold:" : "Upper Threshold:"); display.display();

while (true) {
char key = keypad.getKey();
if (key) {
if (key == ’A’) { if (!negative && inputStr.length()==0) { negative = true; Serial.print("-"); } }
else if (key == ’B’) { if (!decimalPointUsed) { decimalPointUsed = true; if(inputStr.length()==0){inputStr +="0";} inputStr+="."; Serial.print("."); } }
else if (key >= ’0’ && key <= ’9’) { inputStr += key; Serial. print(key); }
else if (key == ’D’) { if(inputStr.length()>0){inputStr.remove (inputStr.length()-1);} else if(negative){negative=false;} }
else if (key == ’C’) { break; }
}
delay(10);
}

float value = inputStr.toFloat(); if (negative) value = -value;

return value;
}

// =============================== // Setup
// =============================== void setup() {
Serial.begin(115200);

pinMode(BUZZER_PIN, OUTPUT); digitalWrite(BUZZER_PIN, LOW);

pinMode(GREEN_LED, OUTPUT); pinMode(YELLOW_LED, OUTPUT); pinMode(RED_LED, OUTPUT);

Wire.begin(SDA_PIN, SCL_PIN); if(!display.begin(SSD1306_SWITCHCAPVCC, 0x3C)) { Serial.println("SSD1306 not found"); while(true);
}

display.clearDisplay();
display.setTextSize(2);
display.setCursor(10,20);
display.print("OLED OK");
display.display();
delay(1000);

WiFi.mode(WIFI_STA);
if (esp_now_init() != ESP_OK) { Serial.println("Error initializing ESP-NOW"); return; }
esp_now_register_recv_cb(OnDataRecv);

esp_now_peer_info_t peerInfo = {}; memcpy(peerInfo.peer_addr, senderMAC, 6);
peerInfo.channel = 0;
peerInfo.encrypt = false;
if (esp_now_add_peer(&peerInfo) != ESP_OK) { Serial.println(" Failed to add ESP8266 as peer"); return; }

Serial.println("ESP32-S3 Receiver Ready");
}

// ===============================
// Loop
// =============================== void loop() {
char key = keypad.getKey(); if(key == ’*’) {
inThresholdInput = true;

lowerThreshold = inputFloatValue("Enter LOWER threshold: ", true );
upperThreshold = inputFloatValue("Enter UPPER threshold: ", false);
if(upperThreshold < lowerThreshold){ float tmp = upperThreshold; upperThreshold = lowerThreshold; lowerThreshold = tmp; } thresholdsSet = true;
inThresholdInput = false;
}

if(buzzerActive && millis() - lastBuzzToggle > 500) { buzzState = !buzzState;
digitalWrite(BUZZER_PIN, buzzState ? HIGH : LOW); lastBuzzToggle = millis();
}

if(dataReceived && millis() - lastPacketTime > DATA_TIMEOUT) dataReceived = false;

display.clearDisplay();
if(!dataReceived) { display.setTextSize(2); display.setCursor (20,20); display.print("NO DATA"); digitalWrite(YELLOW_LED,HIGH ); digitalWrite(GREEN_LED,LOW); digitalWrite(RED_LED,LOW); } else {
digitalWrite(YELLOW_LED,LOW);
display.setTextSize(1);
display.setCursor(0,0);
display.print("Lower:"); display.print(lowerThreshold,1); display.print(" Upper:"); display.print(upperThreshold,1);

display.setTextSize(3);
String tempStr = String(incomingData.temperature,1); int16_t x1, y1; uint16_t w,h; display.getTextBounds(tempStr,0,0,&x1,&y1,&w,&h); display.setCursor((SCREEN_WIDTH-w)/2,(SCREEN_HEIGHT-h)/2); display.print(tempStr);

if(incomingData.temperature >= lowerThreshold && incomingData. temperature <= upperThreshold) { digitalWrite(GREEN_LED,HIGH);
digitalWrite(RED_LED,LOW);
} else {
digitalWrite(GREEN_LED,LOW); if(millis()-lastRedBlink>=500){ redState=!redState; digitalWrite(RED_LED,redState); lastRedBlink=millis(); } }
}
display.display();
delay(50);
}

## 6 Simulation Results

To verify behaviour before hardware testing, a simple simulation was performed showing the expected temperature variation and alert conditions.

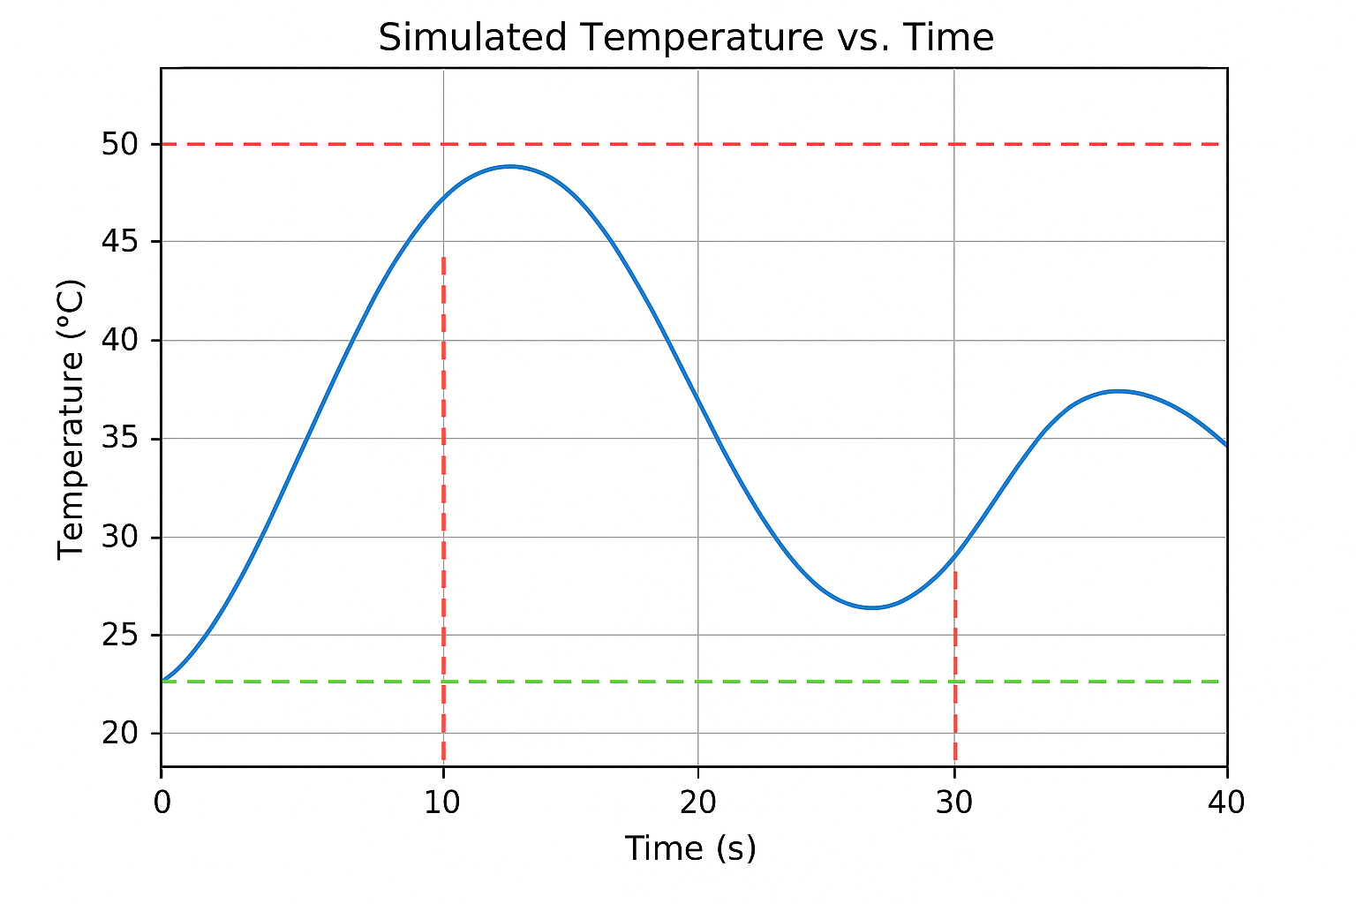
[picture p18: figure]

Figure 10: Simulated temperature vs. time graph showing threshold crossings

Simulation confirmed expected transitions and packet transmission rates.

## 7 Prototype and Testing

### 7.1 Prototype

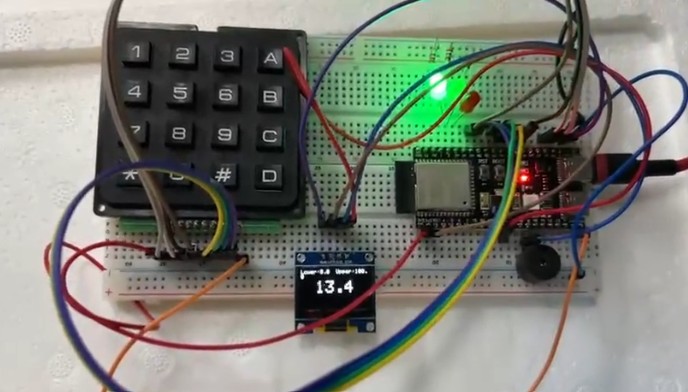
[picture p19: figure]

Figure 11: Prototype of the complete system

### 7.2 Test Results

The prototype was tested under both controlled and outdoor conditions. Key observations include:

- Wireless signal remained stable up to 20–30 m line-of-sight.
- Temperature readings were consistent and stable. A small accuracy deviation of approximately ±0.5

◦C was observed when compared to a calibrated thermometer.

- Visual and audio alerts triggered correctly when temperature thresholds were exceeded.
- Battery performance was sufficient for continuous monitoring during field testing.

Overall, the system demonstrated reliable performance, with only minor sensor accuracy limitations that can be addressed in future improvements.

## 8 Possible Regulatory Pathway

### 8.1 Device Classification

- The device is likely classified as a Class I medical device (low-risk) under FDA regulations, since it only monitors temperature and provides alerts without directly treating or affecting the patient.
- Identify predicate devices with similar intended use and technology, e.g., digital vaccine temperature monitors or data loggers.

### 8.2 Preclinical Testing

- Performance Testing: Validate temperature sensor accuracy, alert response time, wireless communication reliability, and display readability.
- Electrical Safety and EMC: Test compliance with IEC 60601-1 and IEC 60601-1-2 for low-voltage medical electrical equipment.
- Battery and Power Safety: Evaluate Li-ion battery safety, charging circuits, and protection against overcurrent or short-circuit.
- Usability: Conduct human factors testing to ensure healthcare workers can set thresholds, read alerts, and handle the device easily in field conditions.

### 8.3 Software and Cybersecurity

- Comply with IEC 62304 for medical device software lifecycle and document testing of the ESP-NOW communication, threshold alerts, and mobile app integration.
- Ensure basic cybersecurity measures such as secure wireless communication and data integrity for transmitted temperature data.

### 8.4 Premarket Submission (510(k) or Exemption)

- Submit device description, intended use, and performance testing results if required.
- Since the device is low-risk, it may be 510(k)-exempt or require minimal documentation depending on jurisdiction.
- Include labeling specifying proper use, temperature range, and safety precautions.

### 8.5 Manufacturing and Post-market Compliance

- Implement a Quality Management System (QMS) compliant with 21 CFR Part 820 or ISO 13485.
- Register the device and manufacturing facility with the FDA, EU MDR authorities, and Sri Lanka NMRA as required.
- Monitor post-market performance, collect user feedback, and report any malfunctions or safety issues through the appropriate adverse event reporting system.

## 9 Final Budget

Table 1: Final Budget for the Vaccine Cooler Box Project
S/N | Product / Component | Price (LKR / USD)
1 | ESP8266 NodeMCU | 700
2 | ESP32-S3 | 1850
3 | DS18B20 Temperature Sensor | 240
4 | 0.96” OLED Display | 540
5 | 4x4 Keypad | 680
6 | Buzzer | 50
7 | LED Indicators | 30
8 | 18650 Li-ion Battery | 170
9 | Boost Converter Module | 150
10 | Insulated Box / Enclosure Materials | 3000
11 | Wires and Other connectors | 1000
- | Total Cost | 8410

## 10 Task Allocation

Name | Task
Colombage DM | Circuit Designing, Algorithm Development, PCB soldering
Rahman MFA | Wireless Communication configuration, Enclosure Designing
Abishek L | APP development
Suresh S | Documentation

## 11 Conclusion and Final Product

The developed system offers a reliable, low-cost method for monitoring vaccine temperature during transport. It provides real-time feedback, configurable thresholds, wireless alerts, and ease-of-use suitable for rural healthcare workflows.


Figure 12: Final product

## 12 Future Improvements

- Integration of Peltier-based active cooling
- Enhanced insulation materials
- Solar-powered charging module
- Multi-sensor thermal mapping
- Cloud-based data logging

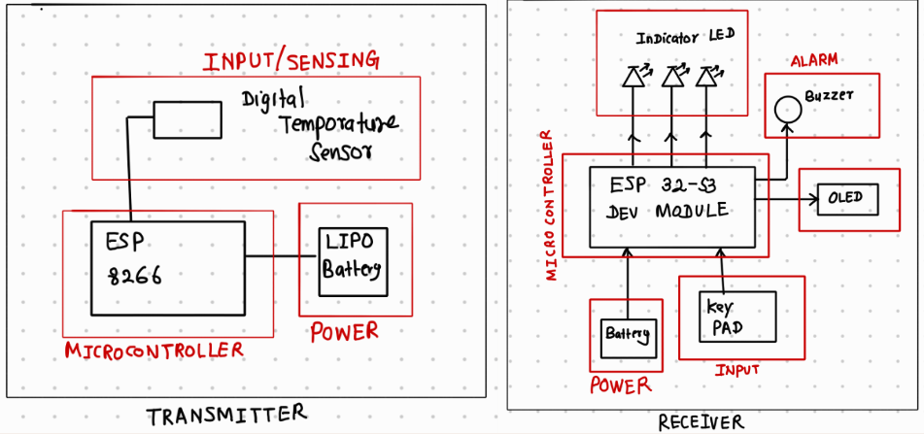
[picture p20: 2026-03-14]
hardware/block_diagram.png

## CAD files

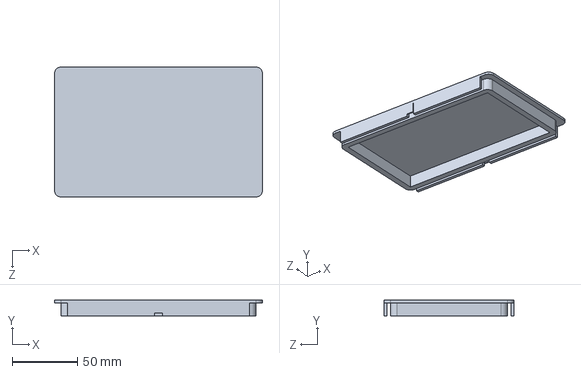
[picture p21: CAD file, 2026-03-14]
solidworks files/Receiver lid.SLDPRT
160.0 x 12.0 x 100.0 mm

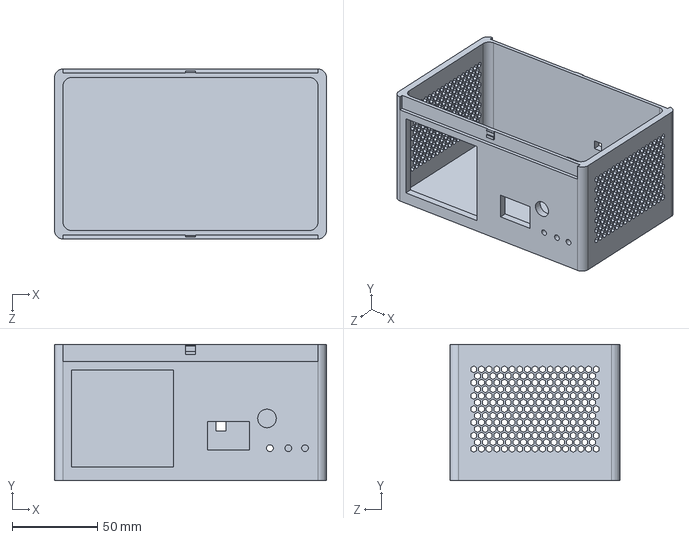
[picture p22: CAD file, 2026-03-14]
solidworks files/Receiver Base.SLDPRT
160.0 x 80.0 x 100.0 mm
